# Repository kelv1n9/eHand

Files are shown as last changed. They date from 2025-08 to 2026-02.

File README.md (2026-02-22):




# 🎙️ eHand

The project is a lightweight handheld digital radio (walkie-talkie) with push-to-talk audio streaming, quick on-device controls via an encoder + PTT button, and several utility modes (scanner, beacon, parrot, SOS) for field use.

---

## ✨ Key Features

### Voice Communication (NRF24L01+)
* **Push-to-Talk (PTT) Audio Streaming:** Live RF audio TX/RX over NRF24L01+.
* **Adjustable RF Data Rate:** `250 kbps`, `1 Mbps`, `2 Mbps` selectable from the device.
* **Adjustable RF Channel:** Cycles through predefined channels (`90`, `100`, `110`).
* **Adjustable TX Power:** `MIN / LOW / HIGH / MAX`.
* **Volume Control:** Local speaker playback volume adjustment.

### Utility Modes
* **Beacon Mode:** Periodic tone transmission with adjustable interval.
* **Parrot Mode:** Measures received audio burst duration and re-transmits it after cooldown.
* **Scanner Mode:** Scans channel + data rate combinations and detects stable incoming signals.
* **SOS Messaging:** Sends/receives a small command packet (`SOS`) and plays an alert tone when received.
* **Roger Beep:** Optional confirmation beep after RX stream ends.

### Device UX / System
* **Encoder + PTT Controls:** Single-device control without screen.
* **LED Feedback System:** Multi-pattern blink codes for battery level, mode changes, and status.
* **Battery Monitoring:** Voltage measurement via `Arduino_Vcc` with low/mid battery indication.
* **EEPROM Settings Persistence:** Saves channel, volume, data rate, TX power, and roger-beep state.
* **PTT Lock:** Lock/unlock transmit flow directly from controls.

---

## 🛠️ Hardware Components

The device is built around a few key parts:
* **MCU:** LGT8F328P
* **2.4 GHz Radio:** **NRF24L01+**
* **Audio Input:** Electret / analog microphone front-end (to `A0`)
* **Audio Output:** Speaker / amplifier driven from PWM audio pin
* **Controls:** Rotary encoder with push switch + separate PTT button
* **Indicator:** Single status LED
* **Power:** Battery-powered handheld design with voltage monitoring

---

## 🔌 Pinout 

### Main Controls / Indicators

| Function | Pin |
|---|---|
| PTT button | `D2` |
| Encoder A | `D4` |
| Encoder B | `D3` |
| Encoder switch | `D5` |
| Status LED | `D6` |
| Speaker (PWM audio out) | `D9` |
| Analog audio input | `A0` |

### NRF24L01+

| Function | Pin |
|---|---|
| CE | `D7` |
| CSN | `D8` |
| SPI | Hardware SPI pins of the board |

Notes:
* `D8` is used as `NRF24 CSN`; keep this in mind when wiring the encoder/speaker section.
* `D9` is used by audio tone/PWM output (speaker / buzzer path).

---

## 🎮 Controls

### Normal Operation

- **PTT hold**: start transmitting audio (push-to-talk)
- **PTT release**: return to receive mode (with short release debounce)
- **Encoder turn** (idle RX): adjust **volume**
- **Encoder press + turn** (idle RX): change **RF channel**
- **PTT hold + encoder turn**: change **TX power**

### Encoder Click Actions (when not transmitting)

- **1 click**: toggle **data rate** (`250k / 1M / 2M`)
- **2 clicks**: enter **Scanner** mode
- **3 clicks**: toggle **Roger Beep**
- **4 clicks**: enter **Beacon** mode
- **5 clicks**: toggle **Parrot** mode

### Extra Actions

- **PTT held + encoder click(s)**: enables **PTT lock** behavior
- **Encoder held** while in **Beacon / Scanner / Parrot**: exit that mode
- **Encoder held + PTT triple-click**: send **SOS** command packet

---

## ⚙️ How It Works

1. **Startup:** The radio is initialized in receive mode, settings are loaded from EEPROM, and LED blinks indicate battery level.
2. **Receive by Default:** The device listens for incoming NRF24 audio payloads or command packets.
3. **PTT Transmit:** Holding PTT switches to TX mode and streams microphone audio over NRF24.
4. **Local Controls:** Encoder actions adjust volume, channel, data rate, TX power, and utility modes.
5. **Utility Modes:** Scanner/Beacon/Parrot reuse the same radio/audio path with mode-specific behavior.
6. **Persistence:** Changed settings are saved to EEPROM after a short delay.

---

## 📁 Project Structure

* `src/main.cpp` — application loop, input handling, mode switching
* `src/functions.h` — feature logic, settings, modes, LED/battery/audio helpers
* `lib/DataTransfer/` — NRF24 audio streaming + command packet transport
* `lib/Tone/` — timer-free tone generation helpers
* `lib/Arduino_Vcc/` — battery voltage measurement
* `3D Model/` — enclosure/mechanical files

---

## 🚨 Disclaimer

> **For Educational & Research Use Only**
> Use this hardware and software responsibly and only on frequencies and systems you are legally allowed to operate on.
> The author accepts no liability for misuse, damage, data loss, or legal consequences.
> **All actions are at your own risk.** Always comply with local laws and regulations.

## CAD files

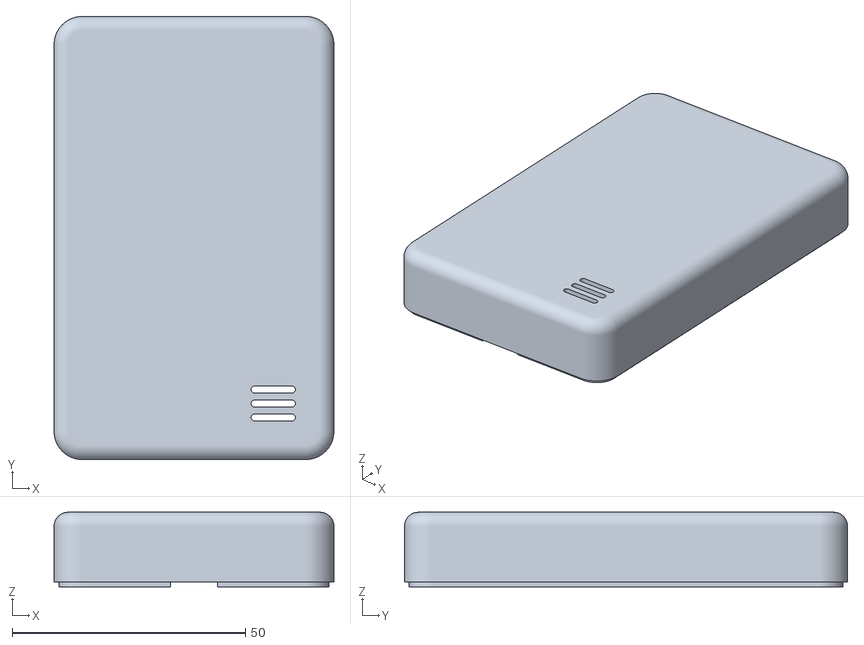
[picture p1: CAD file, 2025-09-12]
3D Model/Bottom_v2.stl
60.0 x 95.0 x 16.0

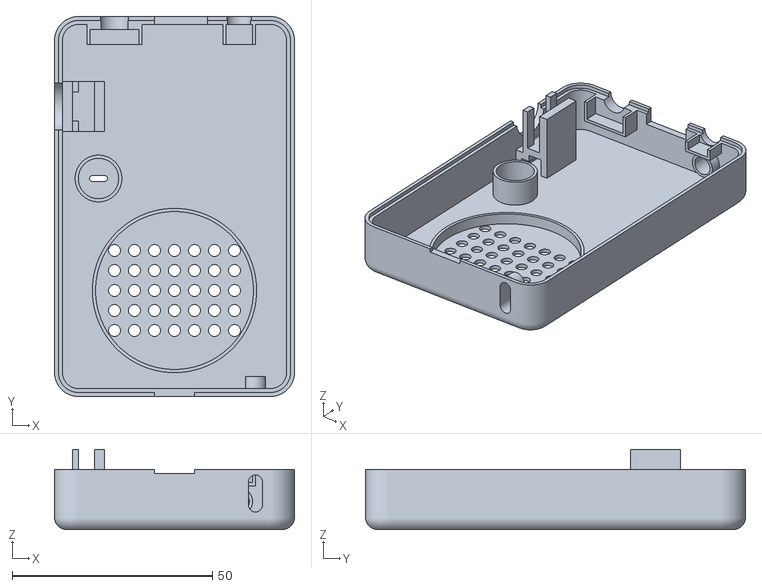
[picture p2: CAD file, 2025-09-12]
3D Model/Top_v2.stl
60.0 x 95.0 x 20.0

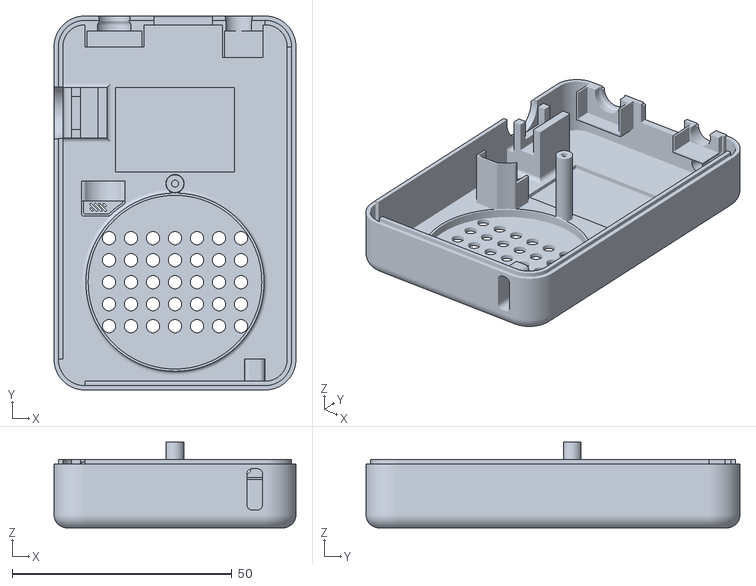
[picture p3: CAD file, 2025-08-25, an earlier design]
3D Model/Top.stl
55.0 x 85.0 x 19.5

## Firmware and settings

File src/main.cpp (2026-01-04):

#include "functions.h"

void setup()
{
#ifdef DEBUG_eHand
  Serial.begin(9600);
  printf_begin();
  delay(1000);
  DBG("Name: %s\n", NAME);
  DBG("Version: %s\n\n", VERSION);
#endif
  RadioBegin();
  loadSettings();
  blinker.begin();

  uint16_t volts = vcc.Read_Volts() * 1000;
  DBG("Battery: %u mV\n", volts);

  if (volts > MID_BATT_VOLT)
    blinker.startEx(1, 100, 100, 0, 2000, false);
  else if (volts > LOW_BATT_VOLT)
    blinker.startEx(2, 100, 100, 0, 2000, false);
  else
    blinker.startEx(3, 100, 100, 0, 2000, false);
}

void loop()
{
  encoder.tick();
  PTT.tick();

  if (beacon.enabled)
  {
    if (encoder.hold())
    {
      beacon.exit();
      return;
    }

    if (encoder.turn())
    {
      int period = beaconPeriod + BEACON_ON_MS * encoder.dir();
      if (period <= BEACON_ON_MS)
        period = BEACON_ON_MS;
      if (period >= BEACON_PERIOD_MAX_MS)
        period = BEACON_PERIOD_MAX_MS;

      beaconPeriod = period;
    }

    beacon.tick();
    blinker.tick();
    return;
  }
  else if (parrot.enabled)
  {
    if (encoder.hold())
    {
      parrot.toggle();
      return;
    }
    parrot.tick();
    blinker.tick();
    return;
  }
  else if (scanner.enabled)
  {
    if (encoder.hold())
    {
      scanner.exit();
      return;
    }
    scanner.tick();
    blinker.tick();
    return;
  }

  // Power toggle when encoder turned while PTT held
  if (PTT.pressing() && encoder.turn())
  {
    if (blinker.active())
      blinker.stop();
    int idx = (int)txPowerIdx + (encoder.dir() > 0 ? 1 : -1);
    if (idx < 0)
      idx = 3;
    if (idx > 3)
      idx = 0;
    config.txPowerIdx = txPowerIdx = (uint8_t)idx;
    applyTxPower();
    markConfigEdited();
    blinker.startEx(txPowerIdx + 1, 200, 200, 200, 200, true);
  }
  else if (!PTT.pressing() && encoder.turn())
  {
    // Channel toggle when encoder pressed and turned
    if (encoder.pressing() && !isTx)
    {
      int newIndex = (int)channelIdx + encoder.dir();

      if (newIndex < 0)
        newIndex = CHANNEL_COUNT - 1;
      if (newIndex >= (int)CHANNEL_COUNT)
        newIndex = 0;

      channelIdx = (uint8_t)newIndex;
      config.channel = channel = channels[channelIdx];
      applyChannel();
      markConfigEdited();
      blinker.startEx(channelIdx + 1, 200, 200, 200, 200, isStreaming);
    }
    // Volume toggle when encoder turned
    else if (!isTx)
    {
      int new_volume = (int)volume + encoder.dir();
      if (new_volume < 0)
        new_volume = 0;
      if (new_volume > maxVolume)
        new_volume = maxVolume;

      if (new_volume != volume)
      {
        config.volume = volume = (uint8_t)new_volume;
        applyVolume();
        markConfigEdited();
        blinker.startEx(1, 20, 20, 0, 200, isStreaming);
      }
    }
  }

  if (PTT.pressing() && encoder.hasClicks())
  {
    pttLocked = true;
    DBG("PTT Locked\n");
  }

  if (PTT.hasClicks() && encoder.pressing())
  {
    uint8_t nClicks = PTT.getClicks();

    if (nClicks == 3)
    {
      DBG("Sending SOS...\n");
      uint8_t packet[BUFFER_SIZE] = {0};
      packet[0] = PROTOCOL_HEADER;
      packet[1] = 'S';
      packet[2] = 'O';
      packet[3] = 'S';
      sendMessage(packet);
      blinker.startEx(1, 200, 200, 0, 0, false);
    }
  }

  if (readMessage(receivedPacket))
  {
    if (receivedPacket[0] == PROTOCOL_HEADER)
    {
      if (receivedPacket[1] == 'S' && receivedPacket[2] == 'O' && receivedPacket[3] == 'S')
      {
        DBG("SOS Received\n");
        SOS.start();
      }
    }
  }

  if (!PTT.pressing() && !isTx && encoder.hasClicks())
  {
    uint8_t nClicks = encoder.getClicks();

    // Rate toggle
    if (nClicks == 1)
    {
      dataRateIdx = (dataRateIdx + 1) % 3;
      config.dataRateIdx = dataRateIdx;
      applyDataRate();
      markConfigEdited();
      blinker.startEx(dataRateIdx + 1, 200, 200, 200, 200, false);
    }
    // Scanner mode
    else if (nClicks == 2 && !scanner.enabled)
    {
      scanner.enter();
      return;
    }
    // Roger Beep
    else if (nClicks == 3)
    {
      rogerEnabled = !rogerEnabled;
      config.rogerEnabled = rogerEnabled ? 1 : 0;
      markConfigEdited();
      blinker.startEx(rogerEnabled ? 1 : 2, 120, 120, 0, 0, false);
      DBG("Roger beep: %s\n", rogerEnabled ? "ON" : "OFF");
    }
    // Beacon mode
    else if (nClicks == 4 && !beacon.enabled)
    {
      beacon.enter();
      return;
    }
    // Parrot mode
    else if (nClicks == 5 && !parrot.enabled)
    {
      parrot.toggle();
      return;
    }
  }

  // Start Transmitting while PTT hold
  if (PTT.press() && !encoder.pressing())
  {
    // Transmit if not receiving
    if (!isStreaming && !isTx && !pttLocked)
    {
      transmit();
      digitalWrite(LED_PIN, isInvisibleMode ? LOW : HIGH);
      isTx = true;
      DBG("Transmitting...\n");
    }
    else if (pttLocked)
    {
      pttLocked = false;
      DBG("PTT Lock released\n");
      if (isTx)
      {
        blinker.stop();
        receive();
        isTx = false;
        DBG("Receiving...\n");
      }
    }
  }

  if (PTT.release() && isTx && !pttLocked)
  {
    releasePending = true;
    releaseAt = millis();
  }

  if (releasePending && isTx && !pttLocked)
  {
    if (millis() - releaseAt >= PTT_RELEASE_MS && !PTT.pressing())
    {
      releasePending = false;
      blinker.stop();
      receive();
      isTx = false;
      DBG("Receiving...\n");
    }
    else if (PTT.pressing())
    {
      releasePending = false;
    }
  }

  // Blink LED when radio is waiting
  if (millis() >= nextBlinkAt && !blinker.active() && !isTx && !isStreaming)
  {
    bool isLow = isLowBattery();
    blinker.startEx(isLow ? 2 : 1, 100, 100, 200, 0, false);
    nextBlinkAt = millis() + LED_BLINK_MS;
  }

  // Roger beep
  if (rogerEnabled && prevStreaming && !isStreaming && !rogerLock)
  {
    rogerLock = true;
    playRogerBeep();
  }
  if (!prevStreaming && isStreaming)
  {
    rogerLock = false;
  }
  prevStreaming = isStreaming;

  SOS.tick();
  blinker.tick();
  saveSettings();
}

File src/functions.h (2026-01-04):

#include "EncButton.h"
#include "DataTransfer.h"
#include <TimerFreeTone.h>
#include <EEPROM.h>
#include <Vcc.h>

// #define DEBUG_eHand

#ifdef DEBUG_eHand
#include "printf.h"
#define DBG(...)             \
    do                       \
    {                        \
        printf(__VA_ARGS__); \
    } while (0)
#else
#define DBG(...) \
    do           \
    {            \
    } while (0)
#endif

#define NAME "eHand"
#define VERSION "2.2.0"

// PINS
#define LED_PIN 6
#define PTT_BUTTON_PIN 2
#define ENCODER_A_PIN 4
#define ENCODER_B_PIN 3
#define ENCODER_SWITCH_PIN 5

// CONSTANTS
#define LOW_BATT_VOLT 3600
#define MID_BATT_VOLT 3900
#define BATT_SAMPLE_MS 20000
#define LED_BLINK_MS 10000
#define SAVE_DELAY_MS 10000
#define PTT_RELEASE_MS 50

// Beacon
#define BEACON_TONE 500
#define BEACON_ON_MS 500
#define BEACON_PERIOD_MAX_MS 5000

// PARROT
#define MIN_DURATION_MS 50
#define COOLDOWN_MS 500

// SCANNER
#define DWELL_MS 500

// SOS
#define SOS_FREQ 800
#define SOS_TIME_UNIT 100

const uint8_t channels[] = {90, 100, 110};
#define CHANNEL_COUNT (sizeof(channels) / sizeof(channels[0]))

Vcc vcc(1);

Button PTT(PTT_BUTTON_PIN);
EncButton encoder(ENCODER_A_PIN, ENCODER_B_PIN, ENCODER_SWITCH_PIN);

struct Settings
{
    uint8_t channel;
    uint8_t volume;
    uint8_t dataRateIdx;
    uint8_t txPowerIdx;
    uint8_t rogerEnabled;
} config;

bool isConfigEdited;
bool prevStreaming = false;
bool rogerLock = false;
bool rogerEnabled = true;
bool isTx = false;
bool pttLocked = false;
bool isInvisibleMode = false;
bool releasePending = false;
uint8_t channelIdx = 0;
uint8_t channel = channels[channelIdx];
uint8_t volume = 4;
uint8_t maxVolume = 7;
uint8_t dataRateIdx = 1;
uint8_t txPowerIdx = 2;
uint16_t beaconPeriod = 1000;
uint32_t nextBlinkAt;
uint32_t releaseAt;
uint32_t configLastChangeTime;

uint8_t receivedPacket[BUFFER_SIZE];

// =========================== TRANSMISSION =============================== //

void applyChannel()
{
    radio.setChannel(channel);
    DBG("Channel: %u\n", channel);
}

void applyDataRate()
{
    switch (dataRateIdx)
    {
    case 0:
        radio.setDataRate(RF24_250KBPS);
        DBG("Data Rate: 250kbps\n");
        break;
    case 1:
        radio.setDataRate(RF24_1MBPS);
        DBG("Data Rate: 1Mbps\n");
        break;
    case 2:
        radio.setDataRate(RF24_2MBPS);
        DBG("Data Rate: 2Mbps\n");
        break;
    }
}

void applyTxPower()
{
    switch (txPowerIdx)
    {
    case 0:
        radio.setPALevel(RF24_PA_MIN);
        DBG("Tx Power: MIN\n");
        break;
    case 1:
        radio.setPALevel(RF24_PA_LOW);
        DBG("Tx Power: LOW\n");
        break;
    case 2:
        radio.setPALevel(RF24_PA_HIGH);
        DBG("Tx Power: HIGH\n");
        break;
    case 3:
        radio.setPALevel(RF24_PA_MAX);
        DBG("Tx Power: MAX\n");
        break;
    }
}

void applyVolume()
{
    setVolume(volume);
    DBG("Volume: %u\n", volume);
}

// =========================== BLINKER =============================== //

struct Blinker
{
    enum BlinkState
    {
        BL_IDLE,
        BL_OFF,
        BL_ON,
        BL_POST
    } state = BL_IDLE;

    uint8_t remaining;
    uint8_t start_count;
    uint16_t pre_ms;
    uint16_t post_ms;
    uint16_t off_ms = 200;
    uint16_t on_ms = 200;
    uint32_t tmark;

    bool use_pre;
    bool resume_high;
    bool repeat;
    bool enabled = true;

    void begin()
    {
        pinMode(LED_PIN, OUTPUT);
        digitalWrite(LED_PIN, LOW);
        state = BL_IDLE;
        remaining = 0;
        tmark = 0;
        use_pre = false;
        start_count = 0;
        repeat = false;
    }

    void startEx(uint8_t count, uint16_t on, uint16_t off, uint16_t pre, uint16_t post, bool resumeHigh, bool rep = false)
    {
        if (!enabled)
        {
            return;
        }

        on_ms = on;
        off_ms = off;
        pre_ms = pre;
        post_ms = post;
        resume_high = resumeHigh;

        repeat = rep;
        start_count = count;
        remaining = count;
        state = BL_OFF;
        use_pre = (pre_ms > 0);

        tmark = millis();
    }

    void stop()
    {
        digitalWrite(LED_PIN, LOW);
        state = BL_IDLE;
        remaining = 0;
        use_pre = false;
        repeat = false;
        start_count = 0;
    }

    bool active()
    {
        return state != BL_IDLE;
    }

    void tick()
    {
        if (!enabled)
        {
            if (state != BL_IDLE)
            {
                digitalWrite(LED_PIN, LOW);
                state = BL_IDLE;
                remaining = 0;
                use_pre = false;
            }
            return;
        }

        if (state == BL_IDLE)
            return;

        switch (state)
        {
        case BL_OFF:
        {
            uint16_t wait = use_pre ? pre_ms : off_ms;
            if ((millis() - tmark) >= wait)
            {
                digitalWrite(LED_PIN, HIGH);
                tmark = millis();
                state = BL_ON;
                use_pre = false;
            }
        }
        break;

        case BL_ON:
            if ((millis() - tmark) >= on_ms)
            {
                digitalWrite(LED_PIN, LOW);
                tmark = millis();

                if (remaining > 0)
                    remaining--;

                if (remaining == 0)
                {
                    if (repeat)
                    {
                        remaining = start_count;
                        state = BL_OFF;
                        use_pre = (pre_ms > 0);
                        tmark = millis();
                    }
                    else
                    {
                        state = (post_ms > 0) ? BL_POST : BL_IDLE;
                        if (state == BL_IDLE && resume_high)
                            digitalWrite(LED_PIN, HIGH);
                    }
                }
                else
                {
                    state = BL_OFF;
                }
            }
            break;

        case BL_POST:
            if ((millis() - tmark) >= post_ms)
            {
                if (resume_high)
                    digitalWrite(LED_PIN, HIGH);
                else
                    digitalWrite(LED_PIN, LOW);
                state = BL_IDLE;
            }
            break;

        default:
            break;
        }
    }
} blinker;

// =========================== BEACON =============================== //
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

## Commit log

2025-08-24 Added 3D Model of device
2025-08-25 Added countersunk screw mount
2025-08-25 Added ready STL models
    [Top.stl]
2025-08-26 Increased resolution of stl files
2025-08-27 Updated LED's position and size
2025-08-27 Added LED indications
2025-08-31 Added roger beep and voltage measurement
2025-09-12 Added new version of 3D model
    [Bottom_v2.stl, Top_v2.stl]
2025-09-12 Improved stability and removed signal ouput from pin 10
2025-09-24 Added voltage indicator at start up
2025-09-24 Added LED disabling
2025-10-01 Improved stability and added Listen-Before-Talk
    [functions.h, main.cpp]
2025-10-11 Added scan mode, fix small issues
    [functions.h, main.cpp]
2025-12-28 Bug fixes. Minor improvements. v2.1.1
    [functions.h, main.cpp]
2026-01-01 Version 2.2.0: added possibility to send and receive text message. Added SOS signal and fast blinker during scanning mode. Small improvements and bug fixes.
    [functions.h, main.cpp]
2026-01-04 Removed unnecesaary files. Bug fiixes
    [functions.h, main.cpp]
2026-01-04 Code refactoring and bug fixes
    [functions.h, main.cpp]

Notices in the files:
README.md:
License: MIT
